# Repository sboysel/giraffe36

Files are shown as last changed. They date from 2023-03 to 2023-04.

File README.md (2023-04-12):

# giraffe36

 

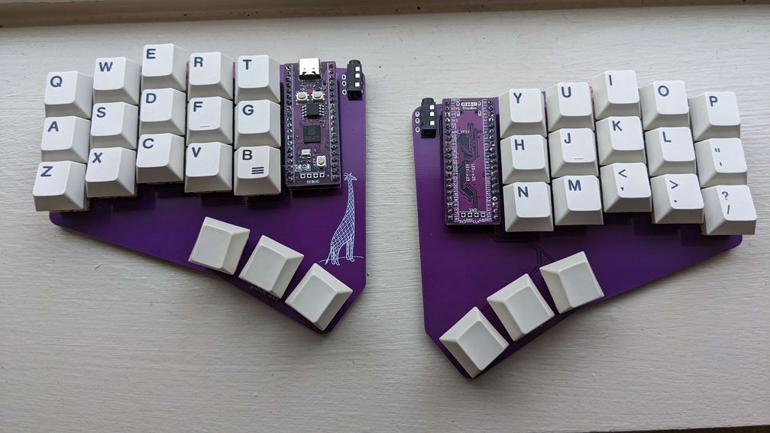
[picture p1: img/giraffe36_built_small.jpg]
pcb front render


A 36 key split keyboard with "long-necked" thumb clusters. Wired, powered by Raspberry Pi Picos, diodeless. Inspirations include Ferris Sweep / sweep36, draculad, samoklava, piantor.

**Status:** [v0.0.1](https://github.com/sboysel/giraffe36/releases/tag/v0.0.1) / [e54525c](https://github.com/sboysel/giraffe36/commit/e54525ce078f5a7b52e7f0cd5a91edfa0f02212c) prototypes have been tested and are functional. See [Tags](https://github.com/sboysel/giraffe36/tags).

## Goals

- simplicity
- declarative design ([ergogen](https://github.com/ergogen/ergogen) and specifically, [my fork](https://github.com/sboysel/ergogen))
- 5x3+3 wired split
- soldered MX to build plateless
- diodeless
- lowered thumb cluster comfortable to my hands
- to learn PCB design!

## Build

BOM

- 2x PCB (they are reversible, fabricated by JLCPCB)
- 2x Raspberry Pi Pico (I used [WeAct Studio Pi Picos](https://www.aliexpress.us/item/3256803521775546.html))
- 2x TRRS PJ-320A jack (4 pins)
- 36x MX switches

Be sure to use the `main` branch. Gerbers can be found in `output/pcbs/routed/`. Archives of the routed PCB and gerbers are located in `output/pcbs/routed/backups`. Firmware ([KMK](http://kmkfw.io/)) can be found in `firmware/kmk/`.

## Development 

Setup

```
git clone git@github.com:sboysel/giraffe36.git
python -m venv --system-site-packages ~/.venv/giraffe36
cd giraffe36
npm install
pip install -r requirements.txt
make
```

The `main` branch contains versions of the board that have been tested and are confirmed to be functional. The `dev` branch contains the latest progress on the next iteration.

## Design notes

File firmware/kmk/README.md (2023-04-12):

# giraffe36 kmk firmware

1. copy CircuitPython to Pi Picos
2. rename L and R
    ```
    sudo umount /dev/sdb1
    sudo fatlabel /dev/sdb1 GIRAFFE36L
    ...
    ```
3. Use Piantor firmware as a starting point
    - https://raw.githubusercontent.com/cairnm/kmk_firmware/piantor/boards/beekeeb/piantor/kb.py
    - https://raw.githubusercontent.com/cairnm/kmk_firmware/piantor/boards/beekeeb/piantor/main.py 

## docs

- https://circuitpython.org/board/weact_studio_pico/
- http://kmkfw.io/docs/split_keyboards/

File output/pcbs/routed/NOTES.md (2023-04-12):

# Fabrication notes

(mostly for myself)

1. Generate unrouted PCBs with ergogen
2. Route in KiCad
  - default track widths
  - add teardrops (defaults)
  - round tracks (defaults)
3. Ground layer
  - front and back copper layer
  - draw polygon outside edge cuts
  - make sure net class GND is selected
  - hatched fill, 45 degree orientation
  - fill all zones at least one final time once all tracks have been routed
4. Export gerbers

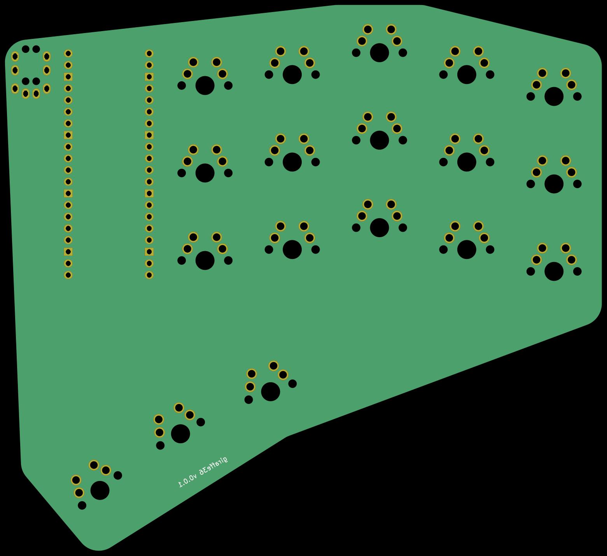
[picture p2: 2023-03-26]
img/giraffe36_pcb_back.jpg

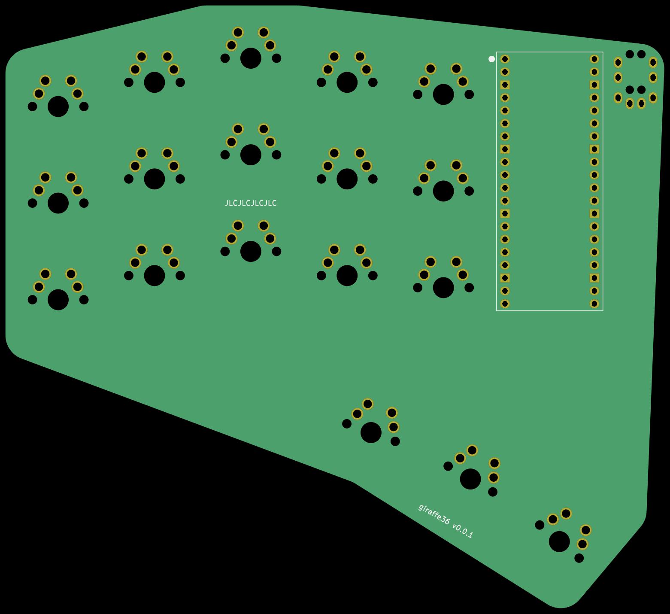
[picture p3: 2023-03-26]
img/giraffe36_pcb_front.jpg

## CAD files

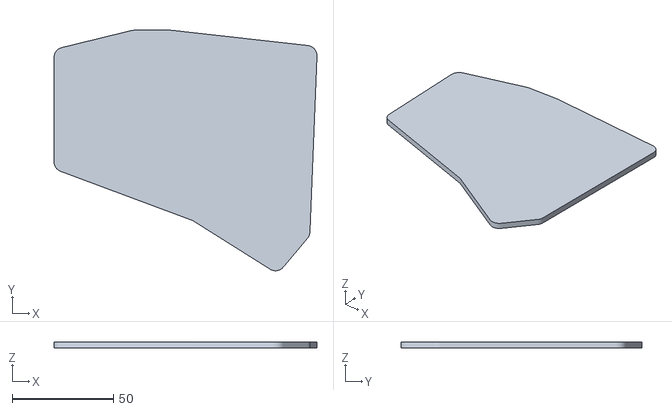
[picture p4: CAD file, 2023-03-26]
output/cases/giraffe36_bottom_case.stl
130.1 x 119.0 x 3.00

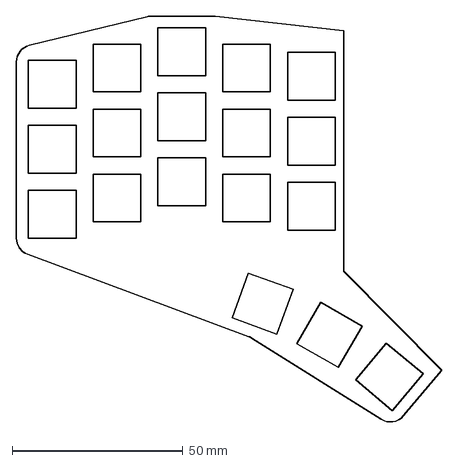
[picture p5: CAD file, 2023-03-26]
output/outlines/giraffe36_top_plate.dxf
124.6 x 119.6 mm

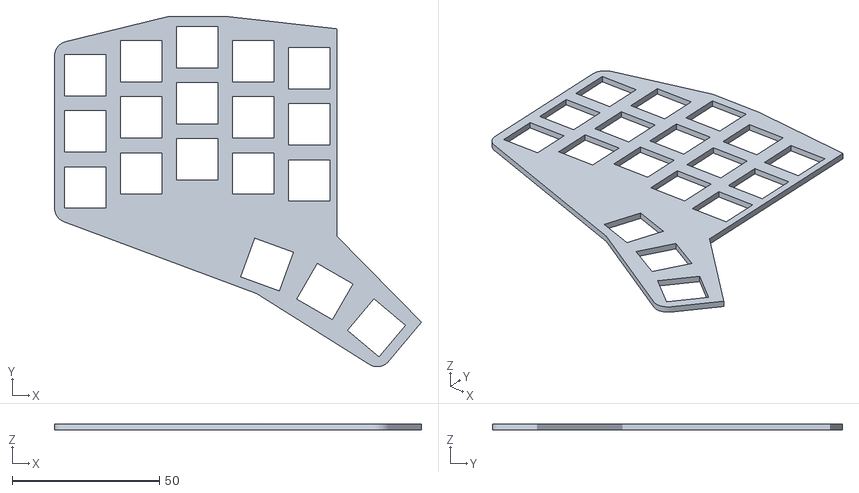
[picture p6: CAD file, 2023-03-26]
output/cases/giraffe36_top_case.stl
124.6 x 119.0 x 2.00

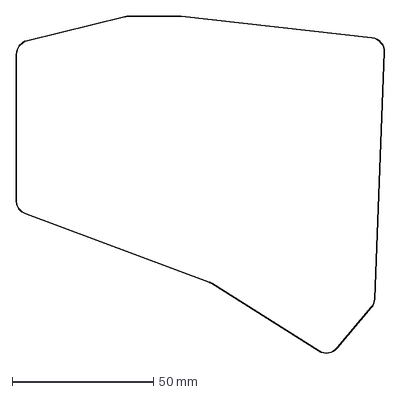
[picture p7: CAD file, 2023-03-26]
output/outlines/giraffe36_bottom_plate.dxf
130.2 x 119.6 mm

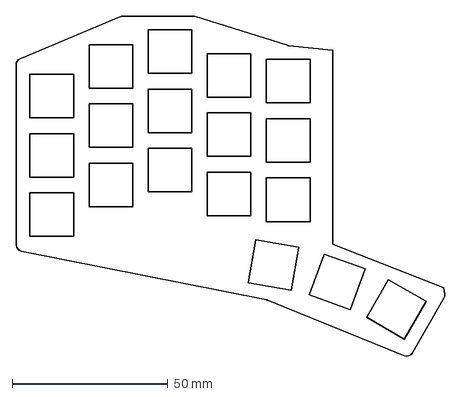
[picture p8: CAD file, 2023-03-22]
output/outlines/otter36_top_plate.dxf
137.7 x 109.6 mm

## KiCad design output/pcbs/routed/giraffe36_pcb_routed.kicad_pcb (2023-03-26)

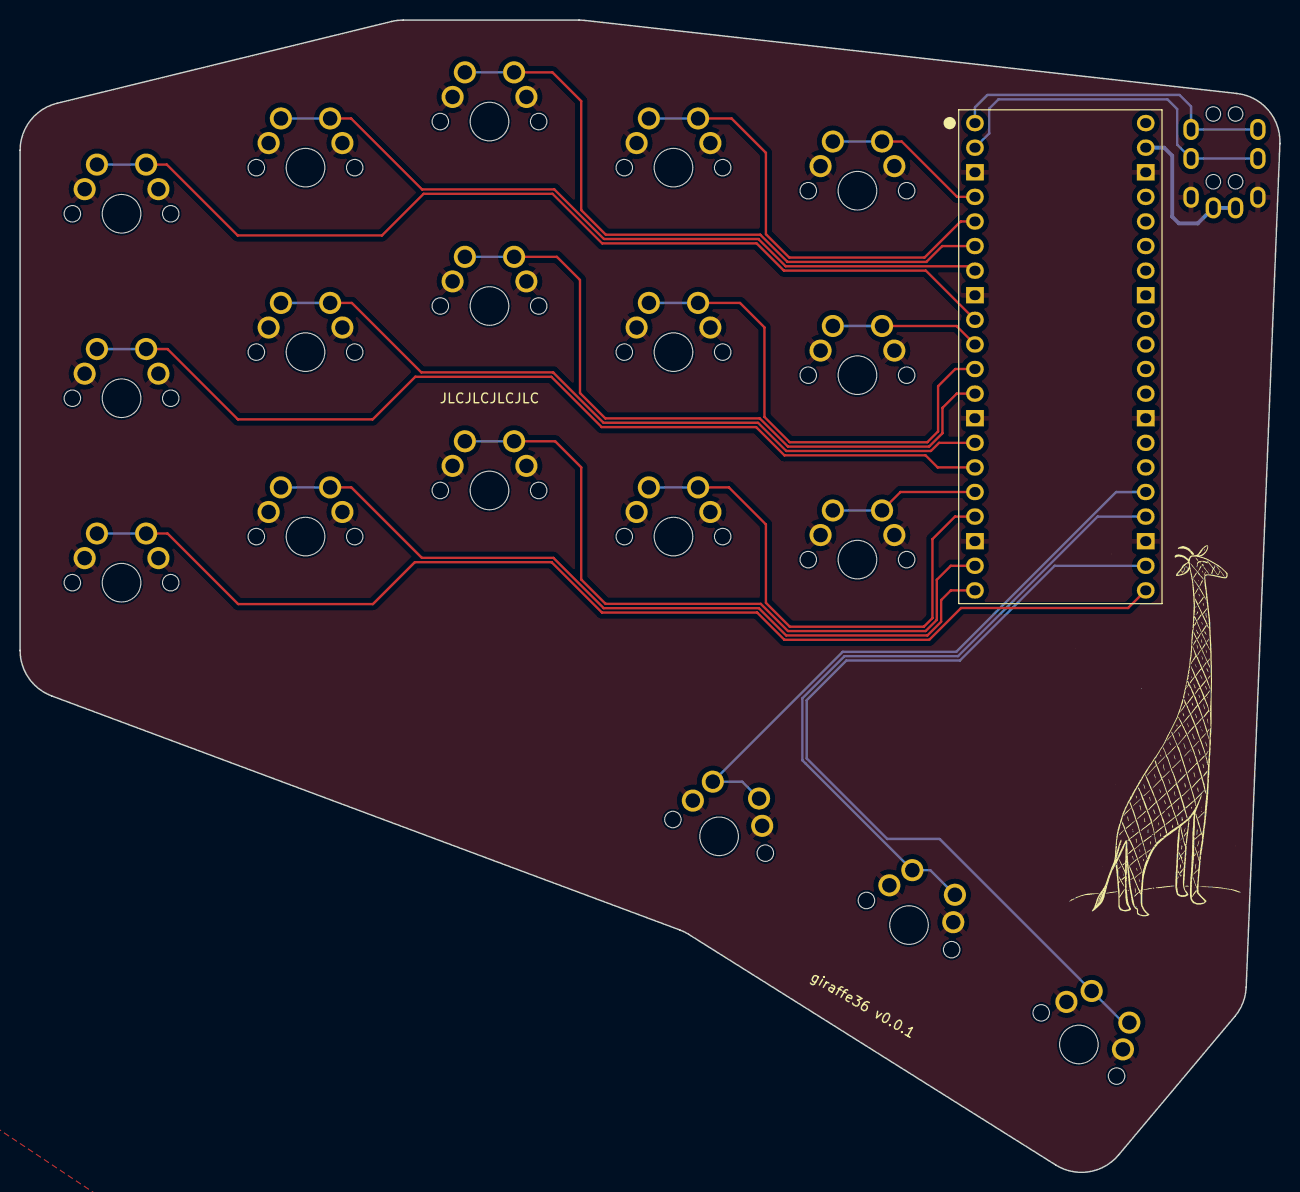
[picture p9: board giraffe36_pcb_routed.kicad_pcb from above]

Board: 2 copper layers, 130.1 x 119.0 mm, 20 parts (0 on the bottom side), 22 nets.

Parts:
S1, S2, S3, S4, S5, S6, S7, S8, S9, S10, S11, S12, S13, S14, S15, S16, S17, S18: MX
TRRS1: TRRS-PJ-320A-dual
U0: Pico; RPi_Pico_TH_oval_face_up

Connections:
GND: S1.2, S2.2, S3.2, S4.2, S5.2, S6.2, S7.2, S8.2, S9.2, S10.2, S11.2, S12.2, S13.2, S14.2, S15.2, S16.2, S17.2, S18.2, TRRS1.2, U0.3, U0.8, U0.13, U0.18, U0.23, U0.28, U0.38
GP0: TRRS1.4, U0.1
GP1: TRRS1.3, U0.2
VSYS: TRRS1.1, U0.39
matrix_index_bottom: S10.1, U0.17
matrix_index_home: S11.1, U0.11
matrix_index_top: S12.1, U0.5
matrix_inner_bottom: S13.1, U0.16
matrix_inner_home: S14.1, U0.10
matrix_inner_top: S15.1, U0.4
matrix_middle_bottom: S7.1, U0.19
matrix_middle_home: S8.1, U0.12
matrix_middle_top: S9.1, U0.6
matrix_pinky_bottom: S1.1, U0.21
matrix_pinky_home: S2.1, U0.15
matrix_pinky_top: S3.1, U0.9
matrix_ring_bottom: S4.1, U0.20
matrix_ring_home: S5.1, U0.14
matrix_ring_top: S6.1, U0.7
thumbfan_far_home: S18.1, U0.22
thumbfan_home_home: S17.1, U0.24
thumbfan_near_home: S16.1, U0.25

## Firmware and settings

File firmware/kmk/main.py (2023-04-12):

import board

from kb import KMKKeyboard, isRight
keyboard = KMKKeyboard()

from kmk.keys import KC
from kmk.modules.split import Split, SplitSide, SplitType
from kmk.modules.layers import Layers; keyboard.modules.append(Layers())
from kmk.modules.modtap import ModTap; keyboard.modules.append(ModTap())
from kmk.modules.mouse_keys import MouseKeys; keyboard.modules.append(MouseKeys())
from kmk.modules.power import Power; keyboard.modules.append(Power())
from kmk.modules.tapdance import TapDance; keyboard.modules.append(TapDance())
from kmk.extensions.media_keys import MediaKeys; keyboard.extensions.append(MediaKeys())
from kmk.modules.capsword import CapsWord; keyboard.modules.append(CapsWord())

keyboard.tap_time = 100

split_side = SplitSide.RIGHT if isRight else SplitSide.LEFT

# data_pin = board.GP1 if split_side == SplitSide.LEFT else board.GP0
# data_pin2 = board.GP0 if split_side == SplitSide.LEFT else board.GP1

split = Split(
    split_side=split_side,
    split_type=SplitType.UART,
    split_flip=True,
    split_target_left=SplitSide.LEFT,
    uart_flip=True,
    data_pin=board.GP1,
    data_pin2=board.GP0,
    use_pio=True,
)
keyboard.modules.append(split)


# === layer tap ---------------------------------------------------------------
# NAV (layer 1)
LT_TAB = KC.LT(1, KC.TAB, prefer_hold=True, tap_interrupted=False, tap_time=200)
LT_SPC = KC.LT(1, KC.SPC, prefer_hold=True, tap_interrupted=False, tap_time=200)
# NUM (layer 2)
LT_BSPC = KC.LT(2, KC.BSPC, prefer_hold=True, tap_interrupted=False, tap_time=200)
# SYM (layer 3)
LT_ENT = KC.LT(3, KC.ENT, prefer_hold=True, tap_interrupted=False, tap_time=200)
# FUN (layer 4)
LT_DEL = KC.LT(4, KC.DEL, prefer_hold=True, tap_interrupted=False, tap_time=200)
# MEDIA (layer 5)
LT_ESC = KC.LT(5, KC.ESC, prefer_hold=True, tap_interrupted=False, tap_time=200)

# === home row mods ------------------------------------------------------------
MT_A = KC.MT(KC.A, KC.LGUI, prefer_hold=False, tap_interrupted=True, tap_time=200)
MT_S = KC.MT(KC.S, KC.LALT, prefer_hold=False, tap_interrupted=True, tap_time=200)
MT_D = KC.MT(KC.D, KC.LCTL, prefer_hold=False, tap_interrupted=True, tap_time=200)
MT_F = KC.MT(KC.F, KC.LSFT, prefer_hold=False, tap_interrupted=True, tap_time=200)

MT_J = KC.MT(KC.J, KC.LSFT, prefer_hold=False, tap_interrupted=True, tap_time=200)
MT_K = KC.MT(KC.K, KC.LCTL, prefer_hold=False, tap_interrupted=True, tap_time=200)
MT_L = KC.MT(KC.L, KC.LALT, prefer_hold=False, tap_interrupted=True, tap_time=200)
MT_QUOT = KC.MT(KC.QUOT, KC.LGUI, prefer_hold=False, tap_interrupted=True, tap_time=200)

# === keymap -------------------------------------------------------------------
keyboard.keymap = [
    # QWERTY
    [
        KC.Q,    KC.W,    KC.E,    KC.R,    KC.T,       KC.Y,   KC.U,    KC.I,    KC.O,    KC.P,
        MT_A,    MT_S,    MT_D,    MT_F,    KC.G,       KC.H,   MT_J,    MT_K,    MT_L,    MT_QUOT,
        KC.Z,    KC.X,    KC.C,    KC.V,    KC.B,       KC.N,   KC.M,    KC.COMM, KC.DOT,  KC.SLSH,
                          LT_ESC,  LT_SPC,  LT_TAB,     LT_ENT, LT_BSPC, LT_DEL,
    ],                  
    #                     MEDIA             NAV         NUM     SYM      FUN
    # NAV
    [
        KC.NO,   KC.NO,   KC.NO,   KC.NO,   KC.NO,      KC.NO,  KC.NO,   KC.NO,   KC.NO,   KC.NO,
        KC.LGUI, KC.LALT, KC.LCTL, KC.LSFT, KC.NO,      KC.NO,  KC.LEFT, KC.DOWN, KC.UP,   KC.RGHT,
        KC.NO,   KC.RALT, KC.NO,   KC.NO,   KC.NO,      KC.INS, KC.HOME, KC.PGDN, KC.PGUP, KC.END,
                          KC.NO,   KC.NO,   KC.NO,      KC.ENT, KC.BSPC, KC.DEL, 
    ],
    # NUM
    [
        KC.LBRC, KC.N7,   KC.N8,   KC.N9,   KC.RBRC,    KC.NO,  KC.NO,   KC.NO,   KC.NO,   KC.NO,
        KC.SCLN, KC.N4,   KC.N5,   KC.N6,   KC.EQL,     KC.NO,  KC.LSFT, KC.LCTL, KC.LALT, KC.LGUI,
        KC.GRV,  KC.N1,   KC.N2,   KC.N3,   KC.BSLS,    KC.NO,  KC.NO,   KC.NO,   KC.RALT, KC.NO,
                          KC.DOT,  KC.N0,   KC.MINS,    KC.NO,  KC.NO,   KC.NO,
    ],
    # SYM
    [
        KC.LCBR, KC.AMPR, KC.ASTR, KC.LPRN, KC.RCBR,    KC.NO,  KC.NO,   KC.NO,   KC.NO,   KC.NO,
        KC.COLN, KC.DLR,  KC.PERC, KC.CIRC, KC.PLUS,    KC.NO,  KC.LSFT, KC.LCTL, KC.LALT, KC.LGUI,
        KC.TILD, KC.EXLM, KC.AT,   KC.HASH, KC.PIPE,    KC.NO,  KC.NO,   KC.NO,   KC.RALT, KC.NO,
                          KC.LPRN, KC.RPRN, KC.UNDS,    KC.NO,  KC.NO,   KC.NO,
    ],
    # FUN
    [
        KC.F12,  KC.F7,   KC.F8,   KC.F9,   KC.PSCR,    KC.NO,  KC.NO,   KC.NO,   KC.NO,   KC.NO,
        KC.F11,  KC.F4,   KC.F5,   KC.F6,   KC.SLCK,    KC.NO,  KC.LSFT, KC.LCTL, KC.LALT, KC.LGUI,
        KC.F10,  KC.F1,   KC.F2,   KC.F3,   KC.PAUS,    KC.NO,  KC.NO,   KC.NO,   KC.RALT, KC.NO,
                          KC.APP,  KC.SPC,  KC.TAB,     KC.NO,  KC.NO,   KC.NO,
    ],
    # MEDIA
    [
        KC.NO,   KC.NO,   KC.NO,   KC.NO,   KC.NO,      KC.NO,     KC.NO,   KC.NO,   KC.NO,   KC.NO,
        KC.LGUI, KC.LALT, KC.LCTL, KC.LSFT, KC.NO,      KC.PS_TOG, KC.MPRV, KC.VOLD, KC.VOLU, KC.MNXT,
        KC.NO,   KC.RALT, KC.NO,   KC.NO,   KC.NO,      KC.HID,    KC.NO,   KC.NO,   KC.NO,   KC.NO,
                          KC.NO,   KC.NO,   KC.NO,      KC.MSTP,   KC.MPLY, KC.MUTE,
    ],
]

layer_names_list = [
    'QWERTY', 'NAV', 'NUM', 'SYM', 'FUN', 'MEDIA',
]

if __name__ == '__main__':
    keyboard.go()

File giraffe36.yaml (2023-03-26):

units:
  kx: U
  ky: U

points:
  zones:
    matrix:
      anchor:
        shift: [8kx, -8ky]
      columns:
        pinky:
          key:
            stagger: 0
        ring:
          key:
            stagger: 0.25ky
        middle:
          key:
            stagger: 0.25ky
        index:
          key:
            stagger: -0.25ky
        inner:
          key:
            stagger: -0.125ky
      rows:
        bottom:
        home:
        top:
    thumbfan:
      anchor:
        ref: matrix_inner_bottom
        shift: [-0.75kx, -1.5ky]
      columns:
        near:
          key:
            stagger: 0ky
            splay: -20
        home:
          key:
            stagger: 0ky
            splay: -10
            shift: [0.15kx, -0.075ky]
        far:
          key:
            stagger: 0ky
            splay: -10
            shift: [0.3kx, -0.125ky]
      rows:
        home:
  key:
    padding: ky

outlines:
  _switches:
    - what: rectangle
      where: true
      size: 14
      bound: false
  _mcu_cutout:
    - what: polygon
      points:
        # NW
        - ref: matrix_inner_top
          shift: [0.5kx, 2ky]
        # SW
        - ref: matrix_inner_bottom
          shift: [0.5kx, -1ky]
        # SE
        - ref: thumbfan_far_home
          shift: [1kx, 0.55ky]
        # NE
        - ref: matrix_inner_top
          shift: [4kx, 4ky]
  giraffe36_bottom_plate:
    - what: polygon
      points:
        # NE
        - ref: matrix_inner_top
          shift: [2.3kx, 0.5ky]
        # N
        - ref: matrix_middle_top
          shift: [0.5kx, 0.55ky]
        - ref: matrix_middle_top
          shift: [-0.5kx, 0.55ky]
        # NW
        - ref: matrix_pinky_top
          shift: [-0.55kx, 0.55ky]
        # SW
        - ref: matrix_pinky_bottom
          shift: [-0.55kx, -0.55ky]
        # SE
        - ref: thumbfan_near_home
          shift: [0, -0.55ky]
        - ref: thumbfan_far_home
          shift: [0.55kx, -0.55ky]
        - ref: thumbfan_far_home
          shift: [0.55kx, 0.75ky]
      fillet: 5
  giraffe36_top_plate:
    - giraffe36_bottom_plate 
    - -_mcu_cutout
    - -_switches

pcbs:
  giraffe36_pcb:
    outlines:
      main:
        outline: giraffe36_bottom_plate
        footprints:
    footprints:
      mx:
        what: mx
        where: true
        params:
          keycaps: true
          reverse: true
          hotswap: false 
          from: "{{name}}"
          to: GND
      pico:
        what: weact_pi_pico
        where:
          ref: matrix_inner_bottom
          shift: [1.1kx, 1.1ky]
          rotate: 0
        params:
          orientation: "up"
          GP2: matrix_inner_top
          GP3: matrix_index_top
          GP4: matrix_middle_top
          GP5: matrix_ring_top
          GP6: matrix_pinky_top
          GP7: matrix_inner_home
          GP8: matrix_index_home
          GP9: matrix_middle_home
          GP10: matrix_ring_home
          GP11: matrix_pinky_home
          GP12: matrix_inner_bottom
          GP13: matrix_index_bottom
          GP14: matrix_middle_bottom
          GP15: matrix_ring_bottom
          GP16: matrix_pinky_bottom
          GP17: thumbfan_far_home
          GP18: thumbfan_home_home
          GP19: thumbfan_near_home
      trrs:
        what: trrs
        where:
          ref: matrix_inner_top
          shift: [2.05kx, 0.5ky]
          rotate: 0
        params:
          D: GP0  # sleeve
          C: GP1  # ring 
          B: GND  # ring 
          A: VSYS  # tip
          reverse: true
          symmetric: false
      tagline_front:
        what: text
        where:
          ref: thumbfan_home_home
          shift: [0, -0.5ky]
        params:
          text: 'giraffe36 v0.0.1'
          side: 'F'
      tagline_back:
        what: text
        where:
          ref: thumbfan_home_home
          shift: [0, -0.5ky]
        params:
          text: 'giraffe36 v0.0.1'
          side: 'B'
      jlc_number:
        what: text
        where:
          ref: matrix_middle_home
          shift: [0, -0.5ky]
        params:
          text: 'JLCJLCJLCJLC'
          side: 'F'
      # via:
      #   what: via
      #   where: true
      #   adjust:
      #     shift: [0, -0.25ky]
      #   params:
      #     net: "{{name}}"
      # elitec:
      #   what: elitec
      #   where:
      #     ref: matrix_inner_top
      #     shift: [1.075kx, -0.5ky]
      #     rotate: 270
      #   params:
      #     D3: matrix_index_top
      #     D2: matrix_inner_top
      #     D1: matrix_middle_top
      #     D0: matrix_ring_top
      #     D4: matrix_pinky_top
      #     C6: matrix_middle_home
      #     D7: matrix_index_home
      #     E6: matrix_inner_home
      #     B4: matrix_ring_home
      #     B5: matrix_pinky_home
      #     B7: matrix_middle_bottom
      #     D5: matrix_index_bottom
      #     C7: matrix_inner_bottom
      #     F1: matrix_pinky_bottom
      #     F0: matrix_ring_bottom
      #     B6: thumbfan_near_home
      #     B2: thumbfan_home_home
      #     B3: thumbfan_far_home
      #     # B1: 
      #     # F7:
      #     # F6:
      #     # F5:
      #     # F4:
      #     # VCC:
      #     # RST:
      #     # GND:
      #     # B0:
      # m2_nw:
      #   what: m2
      #   where:
      #     ref: matrix_ring_top
      #     shift: [-0.5kx, -0.5ky]
      # m2_ne:
      #   what: m2
      #   where:
      #     ref: matrix_index_top
      #     shift: [0.5kx, -0.5ky]
      # m2_sw:
      #   what: m2
      #   where:
      #     ref: matrix_ring_bottom
      #     shift: [-0.5kx, -0.5ky]
      # m2_se:
      #   what: m2
      #   where:
      #     ref: matrix_index_bottom
      #     shift: [0.5kx, -0.5ky]
      # m2_thumb:
      #   what: m2
      #   where:
      #     ref: thumbfan_home_home
      #     shift: [0.575kx, 0]


cases:
  giraffe36_bottom_case:
    - what: outline
      name: giraffe36_bottom_plate
      extrude: 3
  giraffe36_top_case:
    - what: outline
      name: giraffe36_top_plate
      extrude: 2 

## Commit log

2023-03-22 rename otter -> giraffe, more thumb splay and fillet
    [giraffe36_bottom_case.stl, giraffe36_bottom_plate.dxf, giraffe36_pcb.kicad_pcb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]
2023-03-22 render pcb preview in green
2023-03-24 tweak outlines and routing
    [giraffe36_bottom_case.stl, giraffe36_bottom_plate.dxf, giraffe36_pcb.kicad_pcb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]
2023-03-25 reduce pinky stagger
    [giraffe36_bottom_case.stl, giraffe36_bottom_plate.dxf, giraffe36_pcb.kicad_pcb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]
2023-03-25 remove hotswap
    [giraffe36_pcb.kicad_pcb]
2023-03-26 preparing for first prototypes
    [giraffe36_bottom_case.stl, giraffe36_bottom_plate.dxf, giraffe36_pcb.kicad_pcb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]
2023-03-26 give TRRS are more routing breathing room
    [giraffe36_bottom_case.stl, giraffe36_bottom_plate.dxf, giraffe36_pcb.kicad_pcb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]
2023-03-26 prototypes are being made
2023-04-12 add where to find gerbers

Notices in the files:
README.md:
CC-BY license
